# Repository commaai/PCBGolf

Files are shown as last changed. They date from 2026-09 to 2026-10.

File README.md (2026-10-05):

<div align="center">
<h1>PCBGolf Challenge</h1>
<h3>How small can you make this PCBA?</h3>
<h3>
  <a href="https://comma.ai/leaderboard#pcbgolf_challenge">Leaderboard</a>
  <span> · </span>
  <a href="https://comma.ai/jobs">comma.ai/jobs</a>
  <span> · </span>
  <a href="https://discord.comma.ai">Discord</a>
  <span> · </span>
  <a href="https://x.com/comma_ai">X</a>
</h3>
</div>

## The Board

The schematic is loosely based on [our panda jungle v2](https://www.comma.ai/shop/panda-jungle), a development and debugging board for comma devices and pandas. This version includes:

* 12V DC input with onboard 5V and 3.3V supplies
* Four [OBD-C](https://github.com/commaai/hardware/blob/master/harness/OBD-C.sch.pdf) device ports with individually controlled power and current monitoring
* Four CAN-FD transceivers and ignition simulation circuitry
* A USB hub and USB-C host connection
* A microcontroller and microSD card slot
* A push button and status LEDs

Explore in your browser with KiCanvas: [PCB layout](https://kicanvas.org/?github=https%3A%2F%2Fgithub.com%2Fcommaai%2FPCBGolf%2Fblob%2Fmaster%2Fpcbgolf.kicad_pcb).

Schematics: [Power](https://kicanvas.org/?github=https%3A%2F%2Fgithub.com%2Fcommaai%2FPCBGolf%2Fblob%2Fmaster%2Fpcbgolf.kicad_sch) · [Microcontroller](https://kicanvas.org/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) · [USB & microSD](https://kicanvas.org/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) · [CAN](https://kicanvas.org/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) · [OBD-C ports](https://kicanvas.org/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)

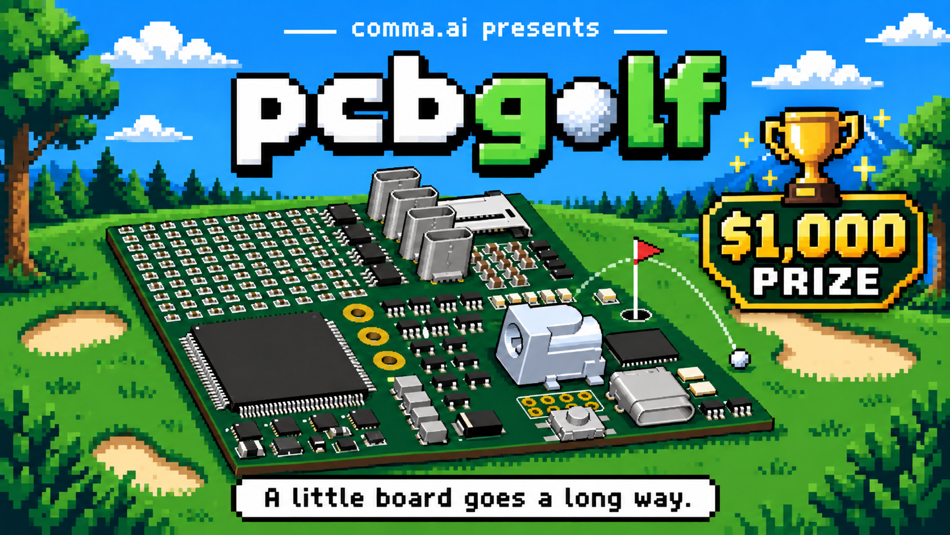
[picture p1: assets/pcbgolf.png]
PCBgolf — A little board goes a long way. $1,000 prize.


## The Challenge

Your goal is to make the most compact, efficient PCBA that retains the same interfaces and functionality as the original design. The lowest score wins.

<p align="center">
  <picture>
    <source media="(prefers-color-scheme: dark)" srcset="./assets/score-dark.svg">
    Score = PCBA bounding box volume (mm³) + 50 × number of vias + 5,000 × number of copper layers.
  </picture>
</p>

### Rules

* The bare PCB(s) must be fully manufacturable by JLCPCB.
* It must be possible to actually assemble the PCBA.
* The assembled product must work and be usable.
* Mating connectors must remain mechanically and electrically compatible.
* Optimizations that require firmware changes are allowed.

### Prize

Lowest score on the [leaderboard](https://comma.ai/leaderboard#pcbgolf_challenge) by **October 12, 2026** wins **$1,000 cash**.

## Submission

Submit a `.zip` file containing your finalized KiCad project and a STEP file of the final assembly [here](https://forms.gle/US88Hg7UR6bBuW3BA).
Competitive scores will be posted on the [leaderboard](https://comma.ai/leaderboard#pcbgolf_challenge) after review. Multiple submissions allowed.

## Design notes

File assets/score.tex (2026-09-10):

\text{Score} = \underbrace{w \times h \times l}_{\text{PCBA bounding box (mm}^3\text{)}} + \underbrace{50\,N_{\text{vias}} + 5{,}000\,N_{\text{copper layers}}}_{N\,=\,\text{count}}

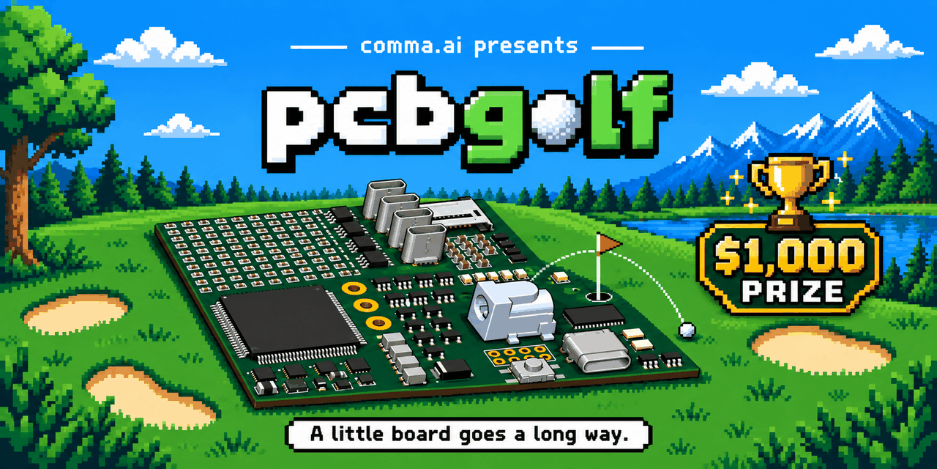
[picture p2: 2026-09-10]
assets/pcbgolf-social.png

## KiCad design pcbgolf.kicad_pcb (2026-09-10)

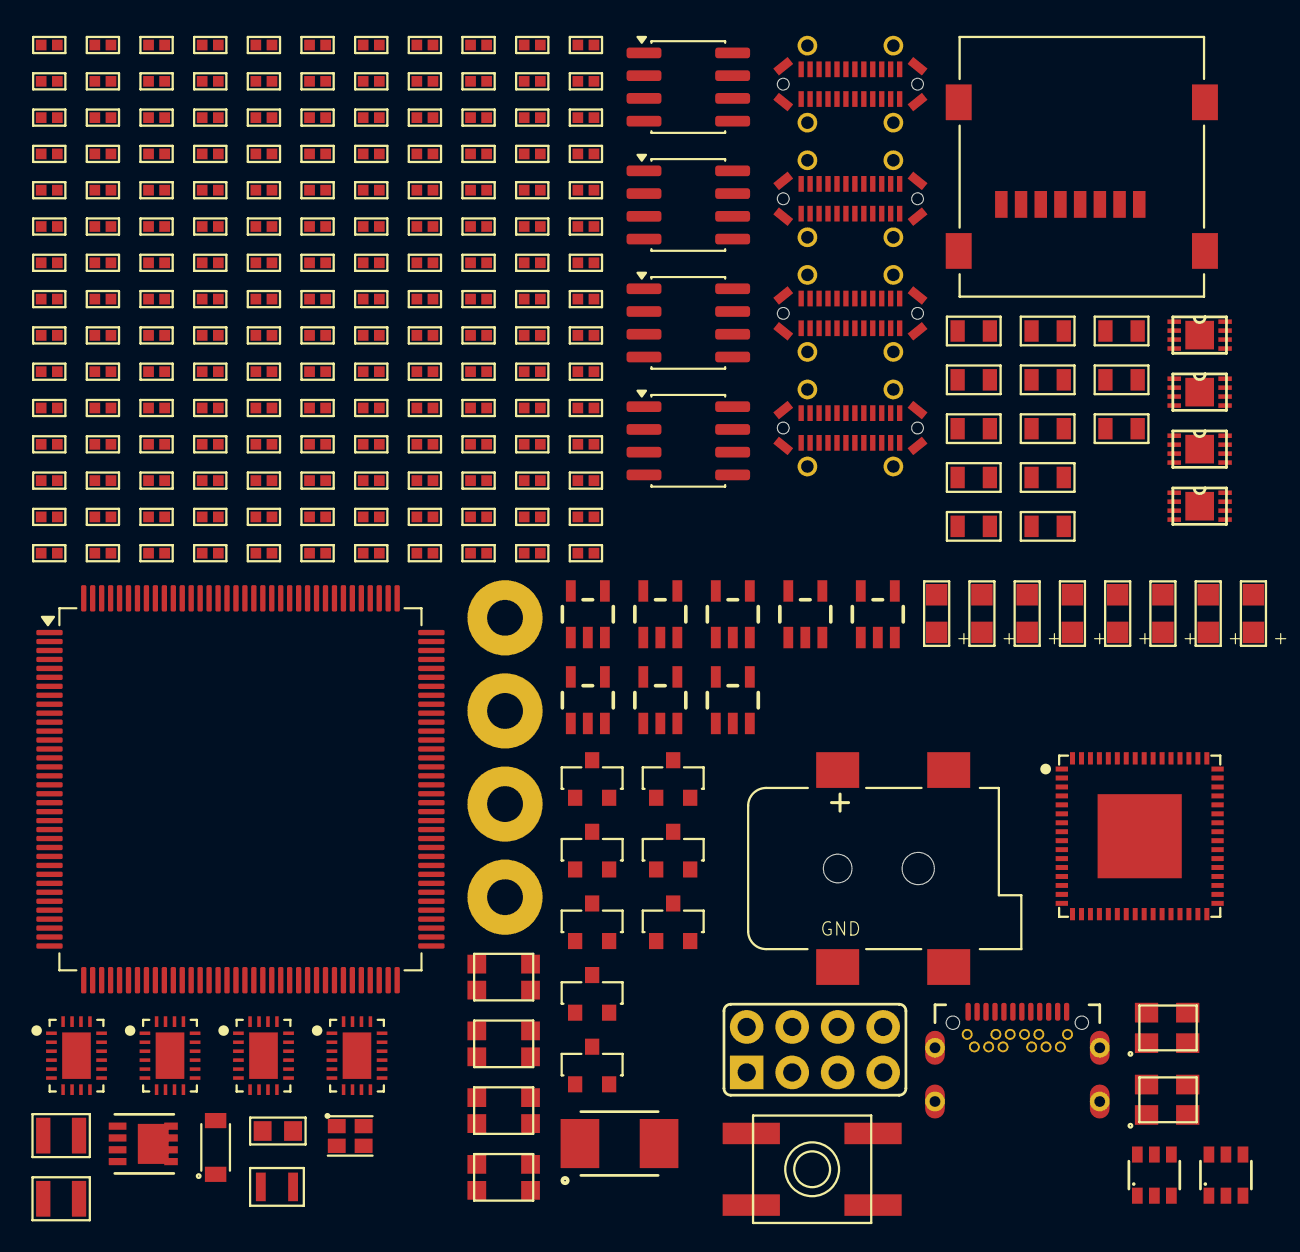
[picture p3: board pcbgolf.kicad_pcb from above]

Board: 2 copper layers, 245 parts (0 on the bottom side), 191 nets, no tracks yet.

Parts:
BH1, BH2, BH3, BH4: M2_BOLT
C1, C3, C8, C12, C13, C15, C19, C20, C21: 10uF; 0805-C
C2, C4, C5, C7, C9, C11, C16, C18, C22, C23, C24, C26, C27, C30, C31, C35, C36, C38, C39, C40, C41, C42, C43, C44, C45, C46, C47, C48, C49: 100nF; 0402-C
C6, C10: DNP; 0402-C
C14, C17, C28, C32: 12pF; 0402-C
C25: 220pF; 0402-C
C29, C33, C34, C37: 10u; 0402-C
C50, C51, C52, C53: 10u; 0805-C
D1: TVS-BI-DO214AA; DO-214AA(SMB)
D2: DIODEDB2W40100L; SOD-123F
J1: DCBARRELSMT; DCJACK_2MM_SMT
J2: MICRO_SD-0472192001; 0472192001
J3: USB-C-FEMALE; DX07S024XJ1R1100
J4: CAN; 2X04
J5, J6, J7, J8: USB-C-FEMALEGCT; USB-C-FEMALE-VERT-GCT
L1, L2: 3u3; L-1008
L3: L-US-L2; 0603-L
L4: 2u2; 0806
L5, L6, L7, L8: ACT1210D_CHOKE; CHOKE-3.2X2.5
LED1: CREE-RGB-CLMVC
LED2: CAN0; CHIPLED
LED3: CAN1; CHIPLED
LED4: CAN2; CHIPLED
LED5: CAN3; CHIPLED
LED6, LED7, LED8, LED9: CH1_PWR; CHIPLED
LED10, LED11, LED12, LED13, LED14, LED15, LED16, LED17: LED-CC-GREEN-RED-AM23ESG; SOT23-3
Q1: SIS427-VI; PP-1212-8
Q2, Q3, Q4, Q5, Q6, Q7, Q8, Q9: NFET-DUAL-COMMON-SOURCE-QS5K2; SOT23-5
R1, R3, R7, R8, R9, R11, R12, R28, R29, R30, R31, R32, R33, R34, R35, R36, R37, R44, R45, R50, R51, R53, R54, R56, R57, R59, R60, R78, R79, R80, R81, R98, R99, R100, R101, R102, R103, R104, R105, R122, R123, R124, R125: 10k; 0402-R
R2, R21, R23, R90, R92, R94, R96, R114, R116, R118, R120: 1k; 0402-R
R4, R5, R6, R13, R14, R15, R16, R17, R18, R19, R20, R24, R25, R52, R55, R58, R61: 100k; 0402-R
R10: 52k3; 0402-R
R22, R62, R63, R64, R65: 2k7; 0402-R
R26: 1M; 0402-R
R27: 12k; 0402-R
R38, R39, R40, R41, R42, R43: 0R; 0402-R
R46, R47, R48, R49: 60; 0402-R
R66, R67, R68, R69: 28k; 0402-R
R70, R71, R72, R73: 33k; 0402-R
R74, R75, R76, R77: 3k3; 0402-R
R82, R83, R84, R85, R86, R87, R88, R89, R91, R93, R95, R97, R106, R107, R108, R109, R110, R111, R112, R113, R115, R117, R119, R121: 100; 0402-R
SW1: SPST-2-4PIN; EVQ-Q2
U1, U2: AP62300T; SOT23-6
U3: STM32H725ZGTx; LQFP-144_20x20mm_P0.5mm
U4: USB2517; QFN64-9X9
U5, U6, U7, U8: MCP2542FDT-E/MNY; TDFN8_2X3MC_MCH
U9, U10, U11, U12: NCS20071XV; SOIC-8_3.9x4.9mm_P1.27mm
U13, U14, U15, U16: TPS25942; WQFN20
Y1: 25MHz; XTAL-3.2X2.5
Y2: 24MHz; XTAL-3.2X2.5

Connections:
+3V3: C6.2, C7.1, C8.1, C19.1, C20.1, C23.1, C24.1, C26.1, C27.1, C30.2, C31.2, C37.1, C42.1, C43.1, C44.1, C45.1, J2.4 (VDD), L1.2, L3.1, LED1.U1 (COM+), R4.1, R5.1, R6.1, R11.1, R28.1, R29.1, R30.1, R33.1, R34.1, R35.1, R36.1, R37.1, SW1.B (S), SW1.B' (S1), U3.7 (VDD), U3.8 (VBAT), U3.13 (VDD), U3.16 (VDDSMPS), U3.19 (VDD), U3.32 (VDD), U3.42 (VDD), U3.56 (VDD), U3.71 (VDD), U3.79 (VDD), U3.90 (VDD50USB), U3.91 (VDD33USB), U3.92 (VDD), U3.106 (VDD), U3.119 (VDD), U3.129 (VDD), U3.144 (VDD), U4.5 (VDDA33), U4.10 (VDDA33), U4.13 (CFG_SEL2), U4.24 (VDD33CR), U4.42 (CFG_SEL1), U4.43 (RESET_N), U4.46 (VDD33), U4.52 (VDDA33), U4.57 (VDDA33), U4.64 (VDD33PLL), U5.5 (VIO), U6.5 (VIO), U7.5 (VIO), U8.5 (VIO)
+5V: C1.1, C2.1, C10.2, C11.1, C12.1, C13.1, C38.1, C39.1, C40.1, C41.1, L2.2, R1.1, R10.2, R52.2, R55.2, R58.2, R61.2, U1.3 (IN), U5.3 (VDD), U6.3 (VDD), U7.3 (VDD), U8.3 (VDD)
+12V: C3.1, C5.1, C46.1, C47.1, C48.1, C49.1, C50.1, C51.1, C52.1, C53.1, D2.1 (C), Q1.1 (S), Q1.2 (S), Q1.3 (S), R7.1, U2.3 (IN), U9.5 (V+), U10.5 (V+), U11.5 (V+), U12.5 (V+), U13.9 (VIN), U13.10 (VIN), U13.11 (VIN), U13.12 (VIN), U13.13 (VIN), U14.9 (VIN), U14.10 (VIN), U14.11 (VIN), U14.12 (VIN), U14.13 (VIN), U15.9 (VIN), U15.10 (VIN), U15.11 (VIN), U15.12 (VIN), U15.13 (VIN), U16.9 (VIN), U16.10 (VIN), U16.11 (VIN), U16.12 (VIN), U16.13 (VIN)
BTN: R12.2, SW1.A, SW1.A' (P1), U3.65 (PE15), U3.135 (BOOT0)
CAN0_EN: U3.134 (PB7), U5.8 (STBY)
CAN0_H: J4.2, J5.A2 (TX1+), J6.A2 (TX1+), J7.A2 (TX1+), J8.A2 (TX1+), L5.4, R46.2, R50.1
CAN0_L: J4.1, J5.A3 (TX1-), J6.A3 (TX1-), J7.A3 (TX1-), J8.A3 (TX1-), L5.3, R46.1, R51.1
CAN0_RX: U3.136 (PB8), U5.4 (RXD)
CAN0_TX: U3.137 (PB9), U5.1 (TXD)
CAN1_EN: U3.130 (PB3(JTDO), U6.8 (STBY)
CAN1_H: J4.4, J5.A11 (RX2+), J6.A11 (RX2+), J7.A11 (RX2+), J8.A11 (RX2+), L6.4, R47.2, R53.1
CAN1_L: J4.3, J5.A10 (RX2-), J6.A10 (RX2-), J7.A10 (RX2-), J8.A10 (RX2-), L6.3, R47.1, R54.1
CAN1_RX: U3.132 (PB5), U6.4 (RXD)
CAN1_TX: U3.133 (PB6), U6.1 (TXD)
CAN2_EN: U3.121 (PD7), U7.8 (STBY)
CAN2_H: J4.6, J5.B2 (TX2+), J6.B2 (TX2+), J7.B2 (TX2+), J8.B2 (TX2+), L7.4, R48.2, R56.1
CAN2_L: J4.5, J5.B3 (TX2-), J6.B3 (TX2-), J7.B3 (TX2-), J8.B3 (TX2-), L7.3, R48.1, R57.1
CAN2_RX: U3.123 (PG10), U7.4 (RXD)
CAN2_TX: U3.122 (PG9), U7.1 (TXD)
CAN3_EN: U3.131 (PB4(NJTRST)), U8.8 (STBY)
CAN3_H: J4.8, J5.B11 (RX1+), J6.B11 (RX1+), J7.B11 (RX1+), J8.B11 (RX1+), L8.4, R49.2, R59.1
CAN3_L: J4.7, J5.B10 (RX1-), J6.B10 (RX1-), J7.B10 (RX1-), J8.B10 (RX1-), L8.3, R49.1, R60.1
CAN3_RX: U3.72 (PB12), U8.4 (RXD)
CAN3_TX: U3.73 (PB13), U8.1 (TXD)
CH1_D_N: J5.A7 (D-A), J5.B7 (D-B), U4.1 (USBDN1_DM)
CH1_D_P: J5.A6 (D+A), J5.B6 (D+B), U4.2 (USBDN1_DP)
CH1_IMON: R70.2, U3.47 (PC4), U13.19 (IMON)
CH1_PWR_EN: U3.37 (PA0), U13.14 (EN)
CH1_SBU1: J5.A8 (SBU1), R19.2, R90.2, R91.2
CH1_SBU1_IGN: Q2.1 (G1), R78.1, R83.2, U3.112 (PD0)
CH1_SBU1_RELAY: Q2.3 (G2), R82.2, R98.2, U3.113 (PD1)
CH1_SBU2: J5.B8 (SBU2), R20.2, R114.2, R115.2
CH1_SBU2_IGN: Q6.1 (G1), R102.1, R107.2, U3.115 (PD3)
CH1_SBU2_RELAY: Q6.3 (G2), R106.2, R122.2, U3.116 (PD4)
CH2_D_N: J6.A7 (D-A), J6.B7 (D-B), U4.3 (USBDN2_DM)
CH2_D_P: J6.A6 (D+A), J6.B6 (D+B), U4.4 (USBDN2_DP)
CH2_IMON: R71.2, U3.50 (PB1), U14.19 (IMON)
CH2_PWR_EN: U3.38 (PA1), U14.14 (EN)
CH2_SBU1: J6.A8 (SBU1), R15.2, R92.2, R93.2
CH2_SBU1_IGN: Q3.1 (G1), R79.1, R85.2, U3.117 (PD5)
CH2_SBU1_RELAY: Q3.3 (G2), R84.2, R99.2, U3.120 (PD6)
CH2_SBU2: J6.B8 (SBU2), R13.2, R116.2, R117.2
CH2_SBU2_IGN: Q7.1 (G1), R103.1, R109.2, U3.76 (PD8)
CH2_SBU2_RELAY: Q7.3 (G2), R108.2, R123.2, U3.78 (PD10)
CH3_D_N: J7.A7 (D-A), J7.B7 (D-B), U4.6 (USBDN3_DM)
CH3_D_P: J7.A6 (D+A), J7.B6 (D+B), U4.7 (USBDN3_DP)
CH3_IMON: R72.2, U3.52 (PF11), U15.19 (IMON)
CH3_PWR_EN: U3.43 (PA4), U15.14 (EN)
CH3_SBU1: J7.A8 (SBU1), R17.2, R94.2, R95.2
CH3_SBU1_IGN: Q4.1 (G1), R80.1, R87.2, U3.82 (PD12)
CH3_SBU1_RELAY: Q4.3 (G2), R86.2, R100.2, U3.81 (PD11)
CH3_SBU2: J7.B8 (SBU2), R18.2, R118.2, R119.2
CH3_SBU2_IGN: Q8.1 (G1), R104.1, R111.2, U3.77 (PD9)
CH3_SBU2_RELAY: Q8.3 (G2), R110.2, R124.2, U3.83 (PD13)
CH4_D_N: J8.A7 (D-A), J8.B7 (D-B), U4.8 (USBDN4_DM)
CH4_D_P: J8.A6 (D+A), J8.B6 (D+B), U4.9 (USBDN4_DP)
CH4_IMON: R73.2, U3.45 (PA6), U16.19 (IMON)
CH4_PWR_EN: U3.44 (PA5), U16.14 (EN)
CH4_SBU1: J8.A8 (SBU1), R16.2, R96.2, R97.2
CH4_SBU1_IGN: Q5.1 (G1), R81.1, R89.2, U3.84 (PD14)
CH4_SBU1_RELAY: Q5.3 (G2), R88.2, R101.2, U3.85 (PD15)
CH4_SBU2: J8.B8 (SBU2), R14.2, R120.2, R121.2
CH4_SBU2_IGN: Q9.1 (G1), R105.1, R113.2, U3.138 (PE0)
CH4_SBU2_RELAY: Q9.3 (G2), R112.2, R125.2, U3.139 (PE1)
GND: BH1.0 (1_0), BH2.0 (1_0), BH3.0 (1_0), BH4.0 (1_0), C1.2, C2.2, C3.2, C5.2, C7.2, C8.2, C11.2, C12.2, C13.2, C14.2, C15.2, C16.2, C17.2, C18.2, C19.2, C20.2, C21.2, C22.2, C23.2, C24.2, C25.2, C26.2, C27.2, C28.2, C29.2, C30.1, C31.1, C32.2, C33.2, C34.2, C35.1, C36.1, C37.2, C38.2, C39.2, C40.2, C41.2, C42.2, C43.2, C44.2, C45.2, C46.2, C47.2, C48.2, C49.2, C50.2, C51.2, C52.2, C53.2, D1.1, J1.GND (GNDBREAK), J1.GNDBREAK (GND), J2.6 (VSS), J2.G1 (GND), J2.G2 (GND), J2.G3 (GND), J2.G4 (GND), J3.A1 (GND), J3.A12 (GND), J3.B1 (GND), J3.B1T (GND), J3.B12 (GND), J3.B12T (GND), J3.S1B (SHIELDA), J3.S1T (SHIELDA), J3.S1TH (SHIELDA), J3.S2B (SHIELDA), J3.S2T (SHIELDA), J3.S2TH (SHIELDA), J3.S3B (SHIELDB), J3.S3T (SHIELDB), J3.S3TH (SHIELDB), J3.S4B (SHIELDB), J3.S4T (SHIELDB), J3.S4TH (SHIELDB), J5.A1 (GND), J5.A12 (GND), J5.B1 (GND), J5.B12 (GND), J5.S1 (SHIELDA), J5.S2 (SHIELDA), J5.S3 (SHIELDA), J5.S4 (SHIELDA), J5.S11 (SHIELDB), J5.S12 (SHIELDB), J5.S13 (SHIELDB), J5.S14 (SHIELDB), J6.A1 (GND), J6.A12 (GND), J6.B1 (GND), J6.B12 (GND), J6.S1 (SHIELDA), J6.S2 (SHIELDA), J6.S3 (SHIELDA), J6.S4 (SHIELDA), J6.S11 (SHIELDB), J6.S12 (SHIELDB), J6.S13 (SHIELDB), J6.S14 (SHIELDB), J7.A1 (GND), J7.A12 (GND), J7.B1 (GND), J7.B12 (GND), J7.S1 (SHIELDA), J7.S2 (SHIELDA), J7.S3 (SHIELDA), J7.S4 (SHIELDA), J7.S11 (SHIELDB), J7.S12 (SHIELDB), J7.S13 (SHIELDB), J7.S14 (SHIELDB), J8.A1 (GND), J8.A12 (GND), J8.B1 (GND), J8.B12 (GND), J8.S1 (SHIELDA), J8.S2 (SHIELDA), J8.S3 (SHIELDA), J8.S4 (SHIELDA), J8.S11 (SHIELDB), J8.S12 (SHIELDB), J8.S13 (SHIELDB), J8.S14 (SHIELDB), LED2.C, LED3.C, LED4.C, LED5.C, LED6.C, LED7.C, LED8.C, LED9.C, LED10.3 (C), LED11.3 (C), LED12.3 (C), LED13.3 (C), LED14.3 (C), LED15.3 (C), LED16.3 (C), LED17.3 (C), Q2.2 (S), Q3.2 (S), Q4.2 (S), Q5.2 (S), Q6.2 (S), Q7.2 (S), Q8.2 (S), Q9.2 (S), R2.1, R3.2, R8.2, R9.2, R12.1, R25.1, R27.1, R31.2, R32.2, R44.2, R45.2, R66.1, R67.1, R68.1, R69.1, R70.1, R71.1, R72.1, R73.1, R78.2, R79.2, R80.2, R81.2, R98.1, R99.1, R100.1, R101.1, R102.2, R103.2, R104.2, R105.2, R122.1, R123.1, R124.1, R125.1, U1.1 (GND), U2.1 (GND), U3.6 (VSS), U3.12 (VSS), U3.14 (VSSSMPS), U3.18 (VSS), U3.33 (VSS), U3.34 (VSSA), U3.41 (VSS), U3.55 (VSS), U3.69 (VSS), U3.80 (VSS), U3.89 (VSS), U3.104 (VSS), U3.118 (VSS), U3.128 (VSS), U3.141 (VSS), U4.19 (TEST), U4.PAD (VSS), U5.2 (VSS), U5.PAD (EPAD), U6.2 (VSS), U6.PAD (EPAD), U7.2 (VSS), U7.PAD (EPAD), U8.2 (VSS), U8.PAD (EPAD), U9.2 (V-), U10.2 (V-), U11.2 (V-), U12.2 (V-), U13.3 (PGTH), U13.15 (OVP), U13.16 (GND), U13.PAD (GND), U14.3 (PGTH), U14.15 (OVP), U14.16 (GND), U14.PAD (GND), U15.3 (PGTH), U15.15 (OVP), U15.16 (GND), U15.PAD (GND), U16.3 (PGTH), U16.15 (OVP), U16.16 (GND), U16.PAD (GND), Y1.2 (3), Y1.4 (3), Y2.2 (3), Y2.4 (3)
HUB_SCL: R30.2, U3.66 (PB10), U4.41 (SCL)
HUB_SDA: R28.2, U3.67 (PB11), U4.40 (SDA)
LED_B: R23.2, U3.1 (PE2)
LED_G: R22.2, U3.2 (PE3)
LED_R: R21.2, U3.3 (PE4)
unnamed: D2.2 (A), Q1.4 (G), R2.2
unnamed: D1.2, J1.PWR1 (PWR), Q1.5 (D), Q1.6 (D), Q1.7 (D), Q1.8 (D), Q1.9 (D)
unnamed: J2.2 (CD/DAT3), R36.2, R41.2
unnamed: J2.5 (CLK), R43.2
unnamed: J2.3 (CMD), R37.2, R42.2
unnamed: J2.7 (DAT0), R33.2, R38.2
unnamed: J2.8 (DAT1), R34.2, R39.2
unnamed: J2.1 (DAT2), R35.2, R40.2
unnamed: J3.A5 (CC1), R31.1, R32.1
unnamed: J3.B5 (CC2), J3.B5T (CC2), R44.1, R45.1
unnamed: J5.A4 (VBUS), J5.A9 (VBUS), J5.B4 (VBUS), J5.B9 (VBUS), R74.1, U13.4 (VOUT), U13.5 (VOUT), U13.6 (VOUT), U13.7 (VOUT), U13.8 (VOUT)
unnamed: J6.A4 (VBUS), J6.A9 (VBUS), J6.B4 (VBUS), J6.B9 (VBUS), R75.1, U14.4 (VOUT), U14.5 (VOUT), U14.6 (VOUT), U14.7 (VOUT), U14.8 (VOUT)
unnamed: J7.A4 (VBUS), J7.A9 (VBUS), J7.B4 (VBUS), J7.B9 (VBUS), R76.1, U15.4 (VOUT), U15.5 (VOUT), U15.6 (VOUT), U15.7 (VOUT), U15.8 (VOUT)
unnamed: J8.A4 (VBUS), J8.A9 (VBUS), J8.B4 (VBUS), J8.B9 (VBUS), R77.1, U16.4 (VOUT), U16.5 (VOUT), U16.6 (VOUT), U16.7 (VOUT), U16.8 (VOUT)
unnamed: LED1.U4 (B-), R23.1
unnamed: LED1.U3 (G-), R22.1
unnamed: LED1.U2 (R-), R21.1
unnamed: LED2.A, R62.2
unnamed: LED3.A, R63.2
unnamed: LED4.A, R64.2
unnamed: LED5.A, R65.2
unnamed: LED6.A, R74.2
unnamed: LED7.A, R75.2
unnamed: LED8.A, R76.2
unnamed: LED9.A, R77.2
unnamed: LED10.2 (AG), R82.1
unnamed: LED10.1 (AR), R83.1
unnamed: LED11.2 (AG), R84.1
unnamed: LED11.1 (AR), R85.1
unnamed: LED12.2 (AG), R86.1
unnamed: LED12.1 (AR), R87.1
unnamed: LED13.2 (AG), R88.1
unnamed: LED13.1 (AR), R89.1
unnamed: LED14.2 (AG), R106.1
unnamed: LED14.1 (AR), R107.1
unnamed: LED15.2 (AG), R108.1
unnamed: LED15.1 (AR), R109.1
unnamed: LED16.2 (AG), R110.1
unnamed: LED16.1 (AR), R111.1
unnamed: LED17.2 (AG), R112.1
unnamed: LED17.1 (AR), R113.1
unnamed: Q2.5 (D1), R90.1
unnamed: Q2.4 (D2), R91.1
unnamed: Q3.5 (D1), R92.1
unnamed: Q3.4 (D2), R93.1
unnamed: Q4.5 (D1), R94.1
unnamed: Q4.4 (D2), R95.1
unnamed: Q5.5 (D1), R96.1
unnamed: Q5.4 (D2), R97.1
unnamed: Q6.5 (D1), R114.1
unnamed: Q6.4 (D2), R115.1
unnamed: Q7.5 (D1), R116.1
unnamed: Q7.4 (D2), R117.1
unnamed: Q8.5 (D1), R118.1
unnamed: Q8.4 (D2), R119.1
unnamed: Q9.5 (D1), R120.1
unnamed: Q9.4 (D2), R121.1
unnamed: R62.1, U9.4
unnamed: R63.1, U10.4
unnamed: R64.1, U11.4
unnamed: R65.1, U12.4
unnamed: C4.1, U1.6 (BST)
unnamed: R1.2, U1.5 (EN)
unnamed: C6.1, R3.1, R4.2, R5.2, R6.2, U1.4 (FB)
unnamed: C4.2, L1.1, U1.2 (SW)
unnamed: C9.1, U2.6 (BST)
unnamed: R7.2, R8.1, U2.5 (EN)
unnamed: C10.1, R9.1, R10.1, U2.4 (FB)
unnamed: C9.2, L2.1, U2.2 (SW)
unnamed: R17.1, U3.28 (PC0)
unnamed: R18.1, U3.29 (PC1)
unnamed: R19.1, U3.30 (PC2_C)
unnamed: R20.1, U3.31 (PC3_C)
unnamed: R11.2, U3.142 (PDR_ON)
unnamed: R13.1, U3.21 (PF7)
unnamed: R14.1, U3.22 (PF8)
unnamed: R15.1, U3.23 (PF9)
unnamed: R16.1, U3.24 (PF10)
unnamed: C14.1, U3.25 (PH0), Y1.1
unnamed: C17.1, U3.26 (PH1), Y1.3 (2)
unnamed: R27.2, U4.63 (RBIAS)
unnamed: R29.2, U4.45 (SUSP_IND)
unnamed: R24.1, R25.2, U4.44 (VBUS_DET)
unnamed: C33.1, C35.2, U4.25 (VDD18)
unnamed: C34.1, C36.2, U4.62 (VDD18PLL)
unnamed: C28.1, R26.2, U4.61 (XTAL1), Y2.1
unnamed: C32.1, R26.1, U4.60 (XTAL2), Y2.3 (2)
unnamed: L5.1, U5.7 (CANH)
unnamed: L5.2, U5.6 (CANL)
unnamed: L6.1, U6.7 (CANH)
unnamed: L6.2, U6.6 (CANL)
unnamed: L7.1, U7.7 (CANH)
unnamed: L7.2, U7.6 (CANL)
unnamed: L8.1, U8.7 (CANH)
unnamed: L8.2, U8.6 (CANL)
unnamed: R50.2, U9.1 (+)
unnamed: R51.2, R52.1, U9.3 (-)
unnamed: R53.2, U10.1 (+)
unnamed: R54.2, R55.1, U10.3 (-)
unnamed: R56.2, U11.1 (+)
unnamed: R57.2, R58.1, U11.3 (-)
unnamed: R59.2, U12.1 (+)
unnamed: R60.2, R61.1, U12.3 (-)
unnamed: R66.2, U13.17 (ILIM)
unnamed: R67.2, U14.17 (ILIM)
unnamed: R68.2, U15.17 (ILIM)
unnamed: R69.2, U16.17 (ILIM)
SD_CLK: R43.1, U3.111 (PC12)
SD_CMD: R42.1, U3.114 (PD2)
SD_D0: R38.1, U3.95 (PC8)
SD_D1: R39.1, U3.96 (PC9)
SD_D2: R40.1, U3.109 (PC10)
SD_D3: R41.1, U3.110 (PC11)
STM_D_N: U3.100 (PA11), U4.55 (USBDN7_DM)
STM_D_P: U3.101 (PA12), U4.56 (USBDN7_DP)
USB_D_N: J3.A7 (D-A), J3.B7 (D-B), J3.B7T (D-B), U4.58 (USBUP_DM)
USB_D_P: J3.A6 (D+A), J3.B6 (D+B), J3.B6T (D+B), U4.59 (USBUP_DP)
VBUS: C29.1, J3.A4 (VBUS), J3.A9 (VBUS), J3.B4 (VBUS), J3.B4T (VBUS), J3.B9 (VBUS), J3.B9T (VBUS), R24.2
VDDA: C22.1, L3.2, U3.35 (VREF+), U3.36 (VDDA)
VDDLDO: C15.1, C16.1, C18.1, C21.1, L4.1, U3.17 (VFBSMPS), U3.68 (VCAP), U3.70 (VDDLDO), U3.103 (VCAP), U3.105 (VDDLDO), U3.140 (VCAP), U3.143 (VDDLDO)
VLXSMPS: C25.1, L4.2, U3.15 (VLXSMPS)

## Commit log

2026-09-10 PCBgolf Challenge
    [pcbgolf.kicad_pcb, pcbgolf.kicad_sch, pcbgolf_2.kicad_sch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]
2026-09-10 clarify assembly rule
2026-09-11 clarify connector compatibility
